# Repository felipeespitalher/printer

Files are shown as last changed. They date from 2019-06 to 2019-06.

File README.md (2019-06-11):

# Folders

## Delta and kossel-mini

These are projects that I collect ideas to build my own 3d printer

## Firmeware

It's a version of Repetier (https://www.repetier.com/). If you need to update any parameter, please, use this tool : https://www.repetier.com/firmware/v100/

# Ramps 1.4

It's a ramps scheme, if you need plug any new tools, use this screenshot as map.

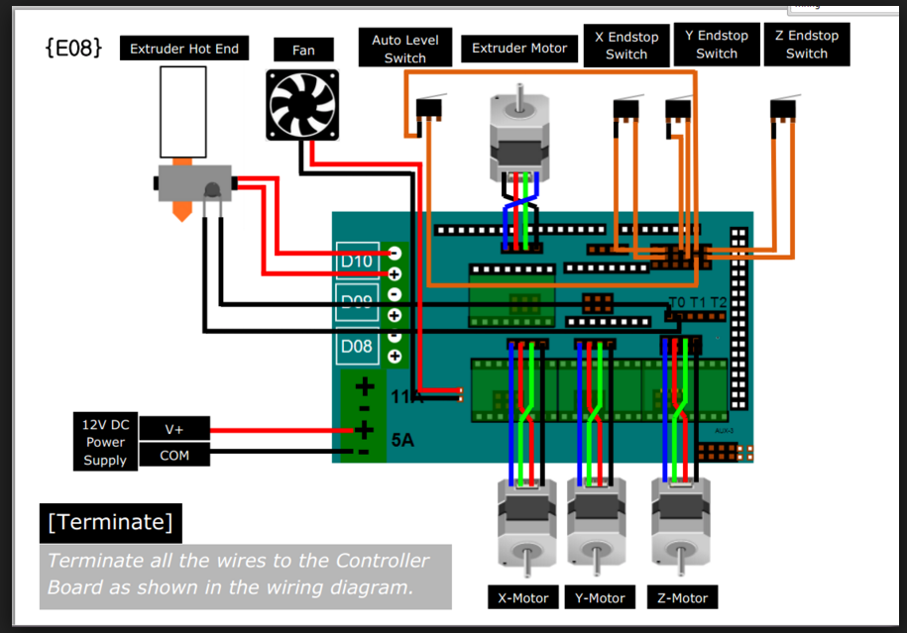
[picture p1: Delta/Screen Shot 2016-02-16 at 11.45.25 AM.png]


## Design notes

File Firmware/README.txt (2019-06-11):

Compilation instructions

1.  Install Arduino IDE
    You get the latest Arduino IDE here:
    http://arduino.cc/en/Main/Software

    You need at least 1.0 for the Atmel AVR based boards and 1.5 for the ARM based boards like the due.

2.  Make sure the serial driver for your printer board is installed. The Arduino IDE contains signed drivers
    for the Arduino boards. Depending on your board you might need different drivers then these. For Linux and Mac
    you often do not need any additional drivers. Ask your printer/board vendor which driver you need,
    if that is not clear to you.

3.  Some boards that are not original arduino boards and not 100% compatible to them, need separate extensions
    to the Arduino IDE. Install them.

4.  Start Arduino IDE and open the file "Repetier.ino"

5.  Select the board and port for upload in the arduino ide.

6.  Check Configuration.h for hints, if something needs to be checked or modified.

7.  Upload the firmware with the upload button (right arrow in toolbar).

If you have a normal mega 2560 compatible board, you can use codeblocks for arduino instead of the arduino ide:
http://arduinodev.com/codeblocks/
Open the Repetier.cbp file instead of the ino file and start with 6.

HINT: It you have enabled eeprom support, the first upload will copy the configurations into the eeprom. Later
uploads will NOT overwrite these settings! Connect with Repetier-Host to your printer and open the eeprom editor
to change these values. Alternatively, send the commands
 M502
 M500
to copy the new values in Configuration.h to eeprom.

IMPORTANT FOR DUE USERS

There is an additional folder AdditionalArduinoFiles with separate readme that describes how to get
watchdog working. It is a very good idea to compile with working watchdog!!!

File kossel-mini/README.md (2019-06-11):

# README #

This README would normally document whatever steps are necessary to get your application up and running.

### What is this repository for? ###

* Quick summary
* Version
* [Learn Markdown](https://bitbucket.org/tutorials/markdowndemo)

### How do I get set up? ###

* Summary of set up
* Configuration
* Dependencies
* Database configuration
* How to run tests
* Deployment instructions

1) Antes de começar, removi a mesa da Rostock, porque fica mais fácil trabalhar no plano da própria base dela. No caso da Kossell é indicado colocar um vidro já que ela não tem base, ou manter a mesa desde que corretamente paralela aos perfis da base. Para desabilitar a mesa é necessário alterar o seguinte

#define TEMP_SENSOR_BED 0

2) Para testar se os motores estavam conectados direito e testar os endstops, instalei o firmware como cartesiana e pelo Pronterface movi cada motor separadamente. Os movimentos X- Y- e Z- movimentaram cada carriage da respectiva coluna para baixo e X+ Y+ Z+, para cima. Se algum motor seu fez movimento diferente, corrija. Enquanto fazia essa operação percebi que não dá para confiar nos dados "padrão" do cálculo dos steps das 3 colunas. No meu caso (polia de 20 dentes, correia GT2, 1/16 de micropasso nos drivers X, Y e Z) o valor calculado devia ser 80, mas ao "mandar andar" o Z, por ex. 50mm, ele andava 55

Como testar uma impressora delta como cartesiana? Comente essas duas linhas e suba novamente o firmware.
//#define DELTA
//#define ENABLE_AUTO_BED_LEVELING

Como descobrir se o "step" das colunas está correto? Peguei o paquímetro e medi a distância do carriage até o topo. Mandei mover o carriage da mesma coluna 50mm e comparei a nova medição com a antiga. Colocando na calculadora do Prusa[4] os dados medidos cheguei ao novo valor, 71.65, que coloquei em

#define DEFAULT_AXIS_STEPS_PER_UNIT   {71.65, 71.65, 71.65, 458}

Com essa mudança os passos ficaram corretos.

ATENÇÃO: O número 458 se refere a relação engrenagem/polia/micropasso do extrusor, no meu caso referente a deste thingiverse[5] e 16 micropassos. Se você usa outra engrenagem, o valor vai ser diferente. Foge ao objetivo deste artigo explicar isso, mas as instruções do cálculo podem ser achadas aqui[6].

OBS: Se a sua plataforma parecer andar "torta" (não ficar paralela a base quando estiver fora do centro), COM CERTEZA os seus "steps" estão errados. Perdi bastante tempo com esse detalhe!!!

3) É bom frisar que os endstops são a parte mais importante de uma impressora delta (bem, junto com os braços serem do exato mesmo tamanho). Os endstops devem estar funcionando perfeitamente, sendo instalados em cima e devidamente conectados na placa na posição de "MAX" dos três eixos. Eles devem permanecer abertos na operação normal e fechados quando o carriage estiver na posição "HOME". Teste com o multímetro se estão assim antes de continuar.

Para uso de endstops mecânicos, é necessário ligar ENDSTOPPULLUPS:

#define ENDSTOPPULLUPS

Deltas só usam endstops de máximo:

#define DISABLE_MIN_ENDSTOPS
//#define DISABLE_MAX_ENDSTOPS

O homing move na direção dos endstops de máximo:

#define X_HOME_DIR 1
#define Y_HOME_DIR 1
#define Z_HOME_DIR 1

Através do comando gcode M119 voce pode observar se os endstops foram reconhecidos e se aparecem "OPEN" na operação normal. Segure cada um deles e repita o M119 para verificar se apareceu "TRIGGERED". É um bom momento para conferir se eles estão ligados nos locais corretos (o endstop do X fica na coluna da esquerda, o endstop do Y na coluna da direita e o do Z na coluna traseira).

4) Agora vamos começar com a configuração de delta, propriamente dita. Para mudar de cartesiana para delta precisamos informar algumas coisas no firmware. Parti dos valores padrão (você deve colocar o ponto decimal nos itens abaixo para que o número seja considerado tipo float pelo compilador do arduino):

#define DELTA
#define ENABLE_AUTO_BED_LEVELING

Valores padrão da Rostock Mini:

#define DELTA_DIAGONAL_ROD 186.0
#define DELTA_SMOOTH_ROD_OFFSET 139.5
#define DELTA_EFFECTOR_OFFSET 33.0
#define DELTA_CARRIAGE_OFFSET 22.0

Valores padrão da Mini Kossel:

#define DELTA_DIAGONAL_ROD 186.0 
#define DELTA_SMOOTH_ROD_OFFSET 128.0 
#define DELTA_EFFECTOR_OFFSET 19.9 
#define DELTA_CARRIAGE_OFFSET 19.5 

5) Sobre o tamanho e posicionamento da mesa, a Rostock Mini tem espaço para uma mesa com cerca de 180mm mas o normal é 160mm. Usei 150mm na configuração para não imprimir colado na borda da minha manta aquecedora. 150mm / 2 são os 75 informados abaixo (X varia de -75 a 75, total 150, Y varia de -75 a 75, total 150mm, lembrando que a área de impressão da delta é REDONDA)

#define DELTA_RADIUS 75

#define X_MAX_POS DELTA_RADIUS
#define X_MIN_POS -DELTA_RADIUS
#define Y_MAX_POS DELTA_RADIUS
#define Y_MIN_POS -DELTA_RADIUS
#define Z_MAX_POS MANUAL_Z_HOME_POS
#define Z_MIN_POS 0

#define MANUAL_HOME_POSITIONS
//#define BED_CENTER_AT_0_0

Não deixaremos o usuário tentar sair do diâmetro da área de impressão para evitar danos aos braços (prevenção nunca é demais):

#define min_software_endstops true
#define max_software_endstops true

O valor do Z_HOME_POS (abaixo) em 196 foi calculada com base na altura do meu bico. O ideal é usar a própria impressora para achar o valor correto, fazendo homing (atraves do gcode G28) e baixando o Z manualmente de 10 em 10mm e depois de 1 em 1mm e 0.1 em 0.1mm até ele tocar na base. Veja a posição final com o gcode M114 e copie o valor correto para o campo. Quando estiver tudo pronto, vai precisar refazer esse passo levando em conta a instalação da mesa aquecida!

#define MANUAL_Z_HOME_POS 196

ATENÇÃO: Por "tocar" me refiro a colocar um cartão na base ou na mesa, o bico encostar nele e você não conseguir puxá-lo sem fazer força. 

6) As acelerações padrões são um pouco altas. Sugiro começar com valores menores e alterar quando a impressora estiver com os movimentos calibrados

#define HOMING_FEEDRATE {900, 900, 900, 0}
#define DEFAULT_MAX_FEEDRATE          {1200, 1200, 1200, 200}
#define DEFAULT_MAX_ACCELERATION      {1500,1500,1500,1500}
#define DEFAULT_ACCELERATION          1200
#define DEFAULT_ZJERK                 DEFAULT_XYJERK

7) Se o seu Marlin tiver o código para M665, M666 e M251 (ou seja, for razoavelmente recente), pode ligar a EEPROM agora retirando o comentário da linha correspondente. Caso contrario deixe para fazer quando terminar. Habilitar o "chitchat" inclui o comando M503, que é bem útil, então procure deixa-lo ligado sempre, tanto em deltas quanto em cartesianas.

//#define EEPROM_SETTINGS
#define EEPROM_CHITCHAT

8) Agora que terminamos as configurações iniciais, compile/suba o firmware e conecte na impressora pelo Pronterface para continuarmos com a calibração

Pelo Pronterface, execute o HOME (G28) e em seguida desça o bico até o Z tocar na base. Anote a posição com o gcode M114 (se você ajustou corretamente o MANUAL_Z_HOME_POS antes, vai ser zero)

Agora execute outro HOME (G28) e mova o bico usando o Pronterface até a plataforma ficar com os braços paralelos as barras verticais da coluna do X (a esquerda). Anote a posição com o GCODE M114. Na minha ficou com os valores abaixo (na sua vai ser com certeza diferente!)

G28
G0 X-71 Y-38 Z-1.1

Agora execute outro HOME (G28) e mova o bico da mesma forma até os braços ficarem paralelos as barras da coluna Y (a da direita). Anote com o M114. Na minha ficou

G28
G0 X69 Y-38 Z-3.7

Finalmente faça o mesmo (G28, mover) até a coluna Z (atrás). Anote com M114. Na minha ficou

G28
G0 X-4 Y83 Z0.4

Se o seu Marlin possui o comando M666, você pode gravar os valores que achou (no meu caso, -1.1, -3.7 e 0.4, no seu caso com certeza serão outros!) ao invés de ajustar manualmente os parafusos dos endstops nos carriages. O comando para isso é (se não tiver habilitado a EPROM precisa executar o comando toda vez que ligar a impressora)

M666 X-1.1 Y-3.7 Z0.4

Se tiver habilitado a EPROM, grave com o gcode M500.

Para saber os valores atuais use o gcode M503

Finalmente, faça um novo home geral (G28) e visite novamente as colunas X, Y e Z usando o Pronterface. O bico deve ficar na mesma distância dessa vez. Se você não tem o comando M666, ajuste o parafuso no carriage de contato com cada endstop e repita o passo 8 novamente até que o movimento das 3 colunas encontrar a mesma altura do Z

9) Agora vem a parte complicada. Faça um novo home (G28) e desça o bico devagar até tocar na base (o lance do cartão novamente!). Se ele chegou lá com Z=0, parabéns!!! Compre um bilhete de loteria agora mesmo!

Caso negativo, vai ser necessário alterar o DELTA_RADIUS. Se o bico tocou na mesa abaixo de 0, o seu DELTA_RADIUS está muito alto, diminua a linha abaixo em alguns milímetros, recompile e repita todo o processo de regulagem das colunas do passo 8.

#define DELTA_SMOOTH_ROD_OFFSET 139.5

Se o bico ficou distante da mesa com Z=0, o seu DELTA_RADIUS está baixo, é necessario AUMENTAR a linha do DELTA_SMOOTH_ROD_OFFSET, recompilar e repetir todo o processo de regulagem das colunas do passo 8.

10) Agora é hora de por a mesa e mover o bico novamente até as 3 colunas, de forma a que a mesa esteja na mesma altura nos três pontos. A minha mesa ficou com 18,8mm. Diminuido do MANUAL_Z_HOME_POS (196) o novo valor ficou 177.2. Agora, ao digitar o gcode G0 Z0 o bico se posiciona no centro da mesa na altura correta

// esse valor vai variar COM A SUA MESA E BICO
#define MANUAL_Z_HOME_POS 177.2

11) Falta agora imprimir a peça de calibração. A sugestão do Minow é o seguinte openscad (stl em anexo):

cube([100,2,2],center=true);

Após imprimir, meça o comprimento do objeto. Se ele estiver errado, será necessário alterar o DELTA_DIAGONAL_ROD usando a seguinte fórmula:

novo_valor = 100 / valor medido em mm * DELTA_DIAGONAL_ROD anterior

Coloque o novo valor (lembrando que precisa do ponto decimal mesmo que seja .0)

#define DELTA_DIAGONAL_ROD novo_valor

recompile, suba novamente o firmware e repita o passo 11.

ANEXO: Como usar o Repetier-Host com delta.

1. Entre no Repetier-Host e clique no botão das engrenagens "Config. da Impressora"
2. Digite "Delta" no campo "Impressora".
3. Clique na aba "Forma da Impressora".
4. Em Printer Type escolha "Rostock Printer"
5. Informe 0 em Home X e Home Y, e escolha MAX em Home Z.
6. Nos campos Printable RADIUS e Printable Height, coloque os mesmos valores de DELTA_RADIUS e MANUAL_Z_HOME_POS que colocou no firmware.
7. Clique em Aplique/OK e está pronto!

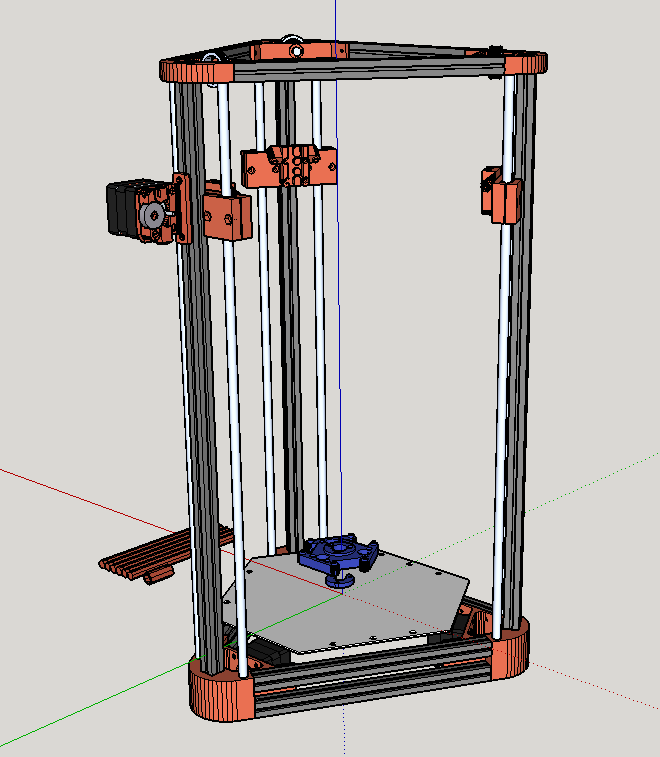
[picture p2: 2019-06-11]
Delta/Screen Shot 2016-03-17 at 2.26.44 PM.png

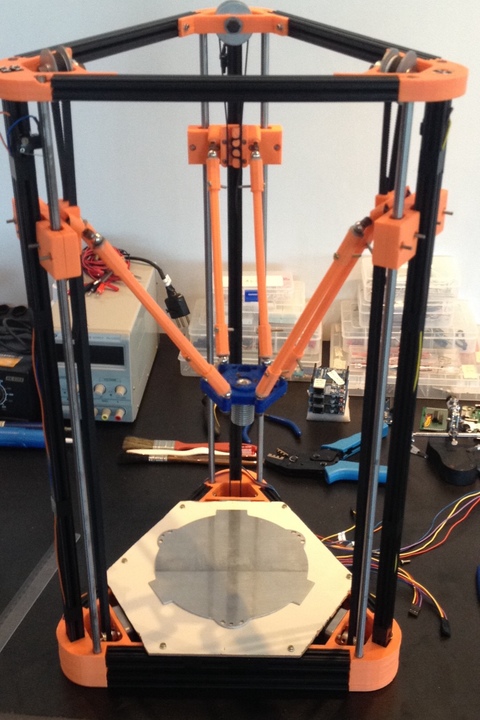
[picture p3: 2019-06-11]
Delta/slack_for_ios_upload_720.jpg

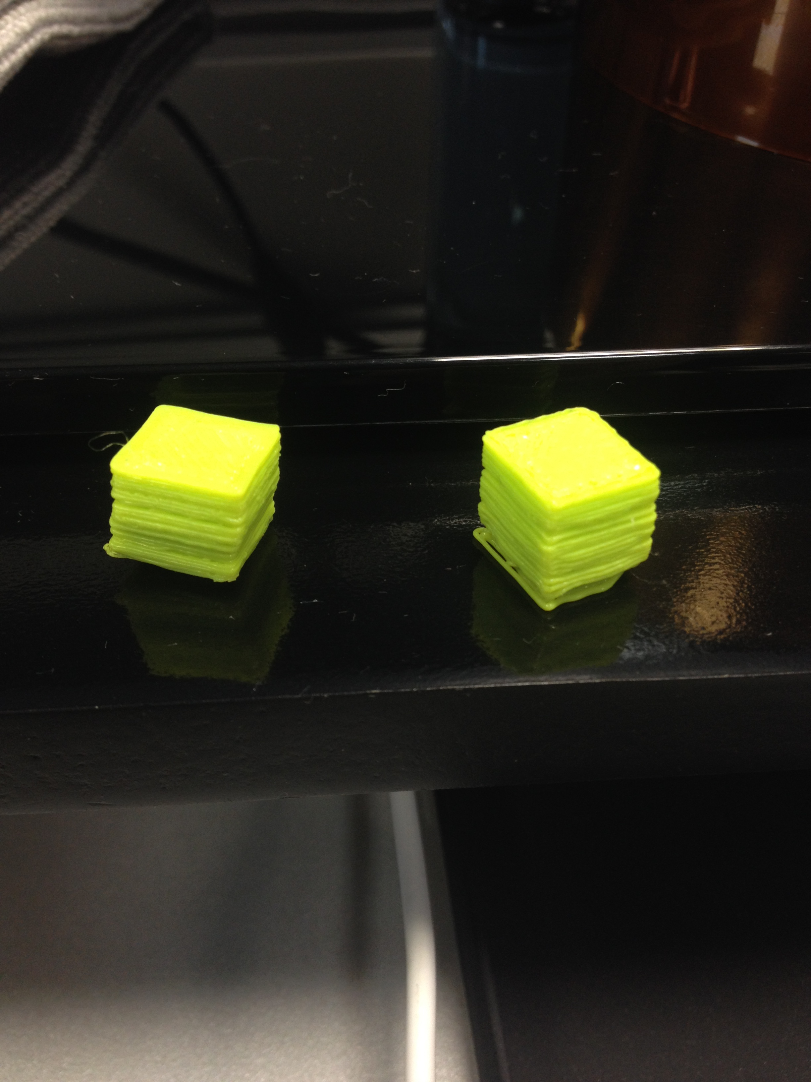
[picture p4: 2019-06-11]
Delta/2016-05-31 10.17.12.jpg

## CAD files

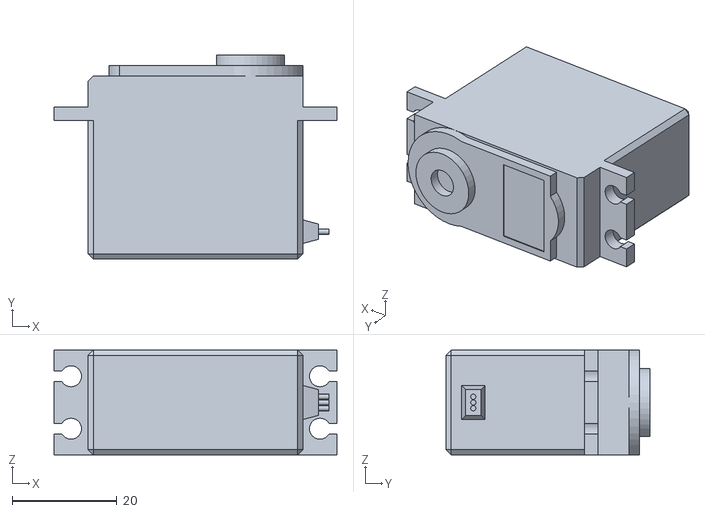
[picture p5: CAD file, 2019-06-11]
MG995-Servo_-_High_torque_Servo-1.STL
54.0 x 39.0 x 20.0

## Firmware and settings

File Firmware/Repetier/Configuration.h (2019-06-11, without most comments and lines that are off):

#define CONFIGURATION_H
#define NUM_EXTRUDER 1
#define MOTHERBOARD 33
#include "pins.h"
#undef FAN_BOARD_PIN
#define FAN_BOARD_PIN -1
#define BOARD_FAN_SPEED 255
#define FAN_THERMO_PIN -1
#define FAN_THERMO_MIN_PWM 128
#define FAN_THERMO_MAX_PWM 255
#define FAN_THERMO_MIN_TEMP 45
#define FAN_THERMO_MAX_TEMP 60
#define FAN_THERMO_THERMISTOR_PIN -1
#define FAN_THERMO_THERMISTOR_TYPE 1
#define BLUETOOTH_SERIAL  -1
#define BLUETOOTH_BAUD  115200
#define MIXING_EXTRUDER 0
#define DRIVE_SYSTEM 3
#define XAXIS_STEPS_PER_MM 80.092762
#define YAXIS_STEPS_PER_MM 80.092762
#define ZAXIS_STEPS_PER_MM 80.092762
#define EXTRUDER_FAN_COOL_TEMP 50
#define PDM_FOR_EXTRUDER 0
#define PDM_FOR_COOLER 0
#define DECOUPLING_TEST_MAX_HOLD_VARIANCE 20
#define DECOUPLING_TEST_MIN_TEMP_RISE 1
#define KILL_IF_SENSOR_DEFECT 0
#define RETRACT_ON_PAUSE 2
#define PAUSE_START_COMMANDS ""
#define PAUSE_END_COMMANDS ""
#define SHARED_EXTRUDER_HEATER 0
#define EXT0_X_OFFSET 10
#define EXT0_Y_OFFSET 0
#define EXT0_Z_OFFSET 0
#define EXT0_STEPS_PER_MM 150
#define EXT0_MAX_FEEDRATE 30
#define EXT0_MAX_START_FEEDRATE 10
#define EXT0_MAX_ACCELERATION 4000
#define EXT0_TEMPSENSOR_TYPE 1
#define EXT0_TEMPSENSOR_PIN TEMP_0_PIN
#define EXT0_HEATER_PIN HEATER_0_PIN
#define EXT0_STEP_PIN ORIG_E0_STEP_PIN
#define EXT0_DIR_PIN ORIG_E0_DIR_PIN
#define EXT0_INVERSE 0
#define EXT0_ENABLE_PIN ORIG_E0_ENABLE_PIN
#define EXT0_ENABLE_ON 0
#define EXT0_HEAT_MANAGER 1
#define EXT0_WATCHPERIOD 1
#define EXT0_PID_INTEGRAL_DRIVE_MAX 140
#define EXT0_PID_INTEGRAL_DRIVE_MIN 60
#define EXT0_PID_PGAIN_OR_DEAD_TIME 24
#define EXT0_PID_I 0.88
#define EXT0_PID_D 80
#define EXT0_PID_MAX 255
#define EXT0_ADVANCE_K 0
#define EXT0_ADVANCE_L 0
#define EXT0_ADVANCE_BACKLASH_STEPS 0
#define EXT0_WAIT_RETRACT_TEMP 190
#define EXT0_WAIT_RETRACT_UNITS 0
#define EXT0_SELECT_COMMANDS ""
#define EXT0_DESELECT_COMMANDS ""
#define EXT0_EXTRUDER_COOLER_PIN -1
#define EXT0_EXTRUDER_COOLER_SPEED 255
#define EXT0_DECOUPLE_TEST_PERIOD 12000
#define EXT0_JAM_PIN -1
#define EXT0_JAM_PULLUP 0
#define FEATURE_RETRACTION 1
#define AUTORETRACT_ENABLED 0
#define RETRACTION_LENGTH 3
#define RETRACTION_LONG_LENGTH 13
#define RETRACTION_SPEED 40
#define RETRACTION_Z_LIFT 0
#define RETRACTION_UNDO_EXTRA_LENGTH 0
#define RETRACTION_UNDO_EXTRA_LONG_LENGTH 0
#define RETRACTION_UNDO_SPEED 20
#define FILAMENTCHANGE_X_POS 0
#define FILAMENTCHANGE_Y_POS 0
#define FILAMENTCHANGE_Z_ADD  2
#define FILAMENTCHANGE_REHOME 1
#define FILAMENTCHANGE_SHORTRETRACT 5
#define FILAMENTCHANGE_LONGRETRACT 50
#define JAM_STEPS 220
#define JAM_SLOWDOWN_STEPS 320
#define JAM_SLOWDOWN_TO 70
#define JAM_ERROR_STEPS 500
#define JAM_MIN_STEPS 10
#define JAM_ACTION 0
#define RETRACT_DURING_HEATUP true
#define PID_CONTROL_RANGE 20
#define SKIP_M109_IF_WITHIN 2
#define SCALE_PID_TO_MAX 0
#define TEMP_HYSTERESIS 0
#define EXTRUDE_MAXLENGTH 160
#define NUM_TEMPS_USERTHERMISTOR0 0
#define USER_THERMISTORTABLE0 {}
#define NUM_TEMPS_USERTHERMISTOR1 0
#define USER_THERMISTORTABLE1 {}
#define NUM_TEMPS_USERTHERMISTOR2 0
#define USER_THERMISTORTABLE2 {}
#define GENERIC_THERM_VREF 5
#define GENERIC_THERM_NUM_ENTRIES 33
#define HEATER_PWM_SPEED 0
#define HAVE_HEATED_BED 0
#define HEATED_BED_MAX_TEMP 120
#define SKIP_M190_IF_WITHIN 3
#define HEATED_BED_SENSOR_TYPE 1
#define HEATED_BED_SENSOR_PIN TEMP_1_PIN
#define HEATED_BED_HEATER_PIN HEATER_1_PIN
#define HEATED_BED_SET_INTERVAL 5000
#define HEATED_BED_HEAT_MANAGER 0
#define HEATED_BED_PID_INTEGRAL_DRIVE_MAX 255
#define HEATED_BED_PID_INTEGRAL_DRIVE_MIN 80
#define HEATED_BED_PID_PGAIN_OR_DEAD_TIME   196
#define HEATED_BED_PID_IGAIN   33
#define HEATED_BED_PID_DGAIN 290
#define HEATED_BED_PID_MAX 255
#define HEATED_BED_DECOUPLE_TEST_PERIOD 300000
#define MIN_EXTRUDER_TEMP 170
#define MAXTEMP 240
#define MIN_DEFECT_TEMPERATURE -10
#define MAX_DEFECT_TEMPERATURE 250
#define SUPPORT_LASER 0
#define LASER_PIN -1
#define LASER_ON_HIGH 1
#define SUPPORT_CNC 0
#define CNC_WAIT_ON_ENABLE 300
#define CNC_WAIT_ON_DISABLE 0
#define CNC_ENABLE_PIN -1
#define CNC_ENABLE_WITH 1
#define CNC_DIRECTION_PIN -1
#define CNC_DIRECTION_CW 1
#define DEFAULT_PRINTER_MODE 0
#define ENDSTOP_PULLUP_X_MIN true
#define ENDSTOP_X_MIN_INVERTING false
#define MIN_HARDWARE_ENDSTOP_X false
#define ENDSTOP_PULLUP_Y_MIN true
#define ENDSTOP_Y_MIN_INVERTING false
#define MIN_HARDWARE_ENDSTOP_Y false
#define ENDSTOP_PULLUP_Z_MIN true
#define ENDSTOP_Z_MIN_INVERTING false
#define MIN_HARDWARE_ENDSTOP_Z false
#define ENDSTOP_PULLUP_X_MAX true
#define ENDSTOP_X_MAX_INVERTING false
#define MAX_HARDWARE_ENDSTOP_X true
#define ENDSTOP_PULLUP_Y_MAX true
#define ENDSTOP_Y_MAX_INVERTING false
#define MAX_HARDWARE_ENDSTOP_Y true
#define ENDSTOP_PULLUP_Z_MAX true
#define ENDSTOP_Z_MAX_INVERTING false
#define MAX_HARDWARE_ENDSTOP_Z true
#define max_software_endstop_r true
#define min_software_endstop_x true
#define min_software_endstop_y true
#define min_software_endstop_z true
#define max_software_endstop_x false
#define max_software_endstop_y false
#define max_software_endstop_z false
#define ENDSTOP_X_BACK_MOVE 5
#define ENDSTOP_Y_BACK_MOVE 5
#define ENDSTOP_Z_BACK_MOVE 2
#define ENDSTOP_X_RETEST_REDUCTION_FACTOR 3
#define ENDSTOP_Y_RETEST_REDUCTION_FACTOR 3
#define ENDSTOP_Z_RETEST_REDUCTION_FACTOR 3
#define ENDSTOP_X_BACK_ON_HOME 1
#define ENDSTOP_Y_BACK_ON_HOME 1
#define ENDSTOP_Z_BACK_ON_HOME 0
#define ALWAYS_CHECK_ENDSTOPS 1
#define X_ENABLE_ON 0
#define Y_ENABLE_ON 0
#define Z_ENABLE_ON 0
#define DISABLE_X 0
#define DISABLE_Y 0
#define DISABLE_Z 0
#define DISABLE_E 0
#define INVERT_X_DIR 0
#define INVERT_Y_DIR 0
#define INVERT_Z_DIR 0
#define X_HOME_DIR -1
#define Y_HOME_DIR -1
#define Z_HOME_DIR 1
#define X_MAX_LENGTH 200
#define Y_MAX_LENGTH 200
#define Z_MAX_LENGTH 230.5
#define X_MIN_POS 0
#define Y_MIN_POS 0
#define Z_MIN_POS 0
#define DISTORTION_CORRECTION 0
#define DISTORTION_CORRECTION_POINTS 5
#define DISTORTION_CORRECTION_R 100
#define DISTORTION_PERMANENT 1
#define DISTORTION_UPDATE_FREQUENCY 15
#define DISTORTION_START_DEGRADE 0.5
#define DISTORTION_END_HEIGHT 1
#define DISTORTION_EXTRAPOLATE_CORNERS 0
#define DISTORTION_XMIN 10
#define DISTORTION_YMIN 10
#define DISTORTION_XMAX 190
#define DISTORTION_YMAX 190
#define FEATURE_BABYSTEPPING 1
#define BABYSTEP_MULTIPLICATOR 1
#define DELTA_SEGMENTS_PER_SECOND_PRINT 180 // Move accurate setting for print moves
#define DELTA_SEGMENTS_PER_SECOND_MOVE 70 // Less accurate setting for other moves
#define EXACT_DELTA_MOVES 1
#define DELTA_DIAGONAL_ROD 200 // mm
#define DELTA_ALPHA_A 210
#define DELTA_ALPHA_B 90
#define DELTA_ALPHA_C 330
#define DELTA_RADIUS_CORRECTION_A 0
#define DELTA_RADIUS_CORRECTION_B 0
#define DELTA_RADIUS_CORRECTION_C 0
#define DELTA_DIAGONAL_CORRECTION_A 0
#define DELTA_DIAGONAL_CORRECTION_B 0
#define DELTA_DIAGONAL_CORRECTION_C 0
#define END_EFFECTOR_HORIZONTAL_OFFSET 0
#define CARRIAGE_HORIZONTAL_OFFSET 0
#define DELTA_MAX_RADIUS 100
#define ROD_RADIUS 105
#define PRINTER_RADIUS 105
#define DELTA_HOME_ON_POWER 0
#define STEP_COUNTER
#define DELTA_X_ENDSTOP_OFFSET_STEPS 0
#define DELTA_Y_ENDSTOP_OFFSET_STEPS 0
#define DELTA_Z_ENDSTOP_OFFSET_STEPS 0
#define DELTA_FLOOR_SAFETY_MARGIN_MM 0.5
#define DELTASEGMENTS_PER_PRINTLINE 24
#define STEPPER_INACTIVE_TIME 360L
#define MAX_INACTIVE_TIME 0L
#define MAX_FEEDRATE_X 200
#define MAX_FEEDRATE_Y 200
#define MAX_FEEDRATE_Z 200
#define HOMING_FEEDRATE_X 40
#define HOMING_FEEDRATE_Y 40
#define HOMING_FEEDRATE_Z 40
#define HOMING_ORDER HOME_ORDER_ZXY
#define ZHOME_MIN_TEMPERATURE 0
#define ZHOME_HEAT_ALL 1
#define ZHOME_HEAT_HEIGHT 20
#define ZHOME_X_POS 999999
#define ZHOME_Y_POS 999999
#define ENABLE_BACKLASH_COMPENSATION 0
#define X_BACKLASH 0
#define Y_BACKLASH 0
#define Z_BACKLASH 0
#define RAMP_ACCELERATION 1
#define STEPPER_HIGH_DELAY 0
#define DIRECTION_DELAY 0
#define STEP_DOUBLER_FREQUENCY 12000
#define ALLOW_QUADSTEPPING 1
#define DOUBLE_STEP_DELAY 0 // time in microseconds
#define MAX_ACCELERATION_UNITS_PER_SQ_SECOND_X 1000
#define MAX_ACCELERATION_UNITS_PER_SQ_SECOND_Y 1000
#define MAX_ACCELERATION_UNITS_PER_SQ_SECOND_Z 1000
#define MAX_TRAVEL_ACCELERATION_UNITS_PER_SQ_SECOND_X 1000
#define MAX_TRAVEL_ACCELERATION_UNITS_PER_SQ_SECOND_Y 1000
#define MAX_TRAVEL_ACCELERATION_UNITS_PER_SQ_SECOND_Z 1000
#define INTERPOLATE_ACCELERATION_WITH_Z 0
#define ACCELERATION_FACTOR_TOP 100
#define MAX_JERK 20
#define MAX_ZJERK 0.3
#define PRINTLINE_CACHE_SIZE 16
#define MOVE_CACHE_LOW 10
#define LOW_TICKS_PER_MOVE 250000
#define EXTRUDER_SWITCH_XY_SPEED 100
#define DUAL_X_AXIS 0
#define FEATURE_TWO_XSTEPPER 0
#define X2_STEP_PIN   ORIG_E1_STEP_PIN
#define X2_DIR_PIN    ORIG_E1_DIR_PIN
#define X2_ENABLE_PIN ORIG_E1_ENABLE_PIN
#define FEATURE_TWO_YSTEPPER 0
#define Y2_STEP_PIN   ORIG_E1_STEP_PIN
#define Y2_DIR_PIN    ORIG_E1_DIR_PIN
#define Y2_ENABLE_PIN ORIG_E1_ENABLE_PIN
#define FEATURE_TWO_ZSTEPPER 0
#define Z2_STEP_PIN   ORIG_E1_STEP_PIN
#define Z2_DIR_PIN    ORIG_E1_DIR_PIN
#define Z2_ENABLE_PIN ORIG_E1_ENABLE_PIN
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

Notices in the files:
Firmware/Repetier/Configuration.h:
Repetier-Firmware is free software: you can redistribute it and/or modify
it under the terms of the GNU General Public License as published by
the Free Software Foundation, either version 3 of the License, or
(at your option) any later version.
